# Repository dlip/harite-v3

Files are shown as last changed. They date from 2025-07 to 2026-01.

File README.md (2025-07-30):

# Harite v3 Directional Keyboard

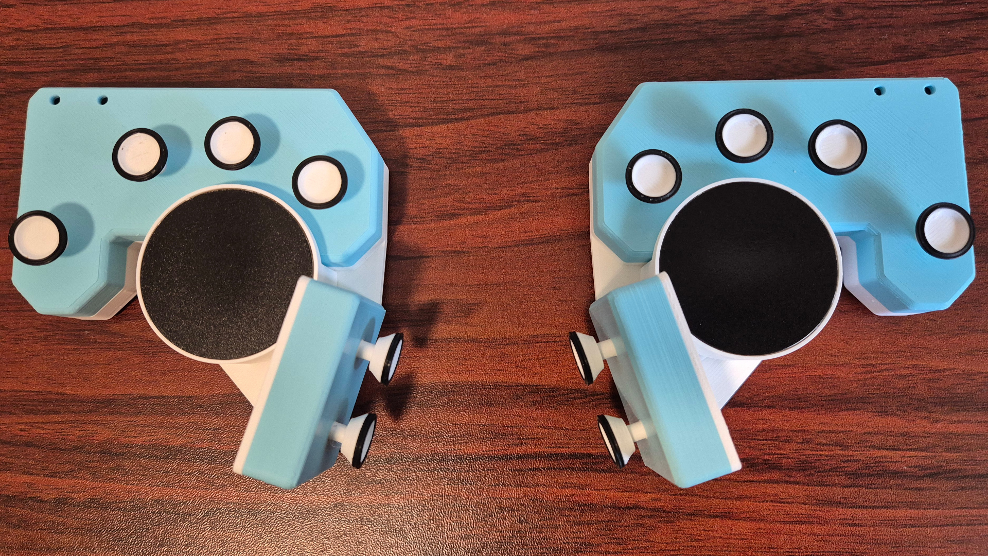
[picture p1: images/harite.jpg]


- 4-way joystick cluster using mouse switches with around 40g actuation force
- 48 total switches
- Bluetooth wireless or USB-C wired
- ZMK studio support for live keymap changes
- Dual trackpads for pointing and scrolling
- Can also support trackballs and analog sticks
- Fully open source and built with open source tools

To make your own, here is a detailed [build guide](./build.md)

## Images

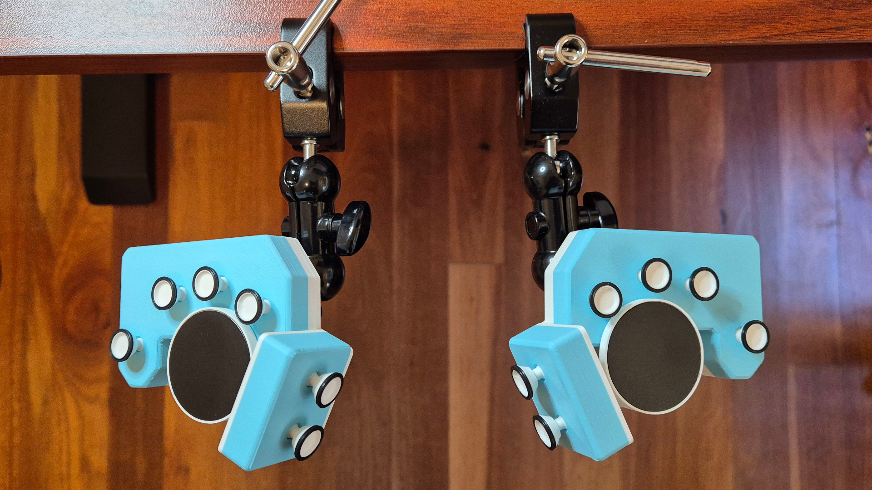
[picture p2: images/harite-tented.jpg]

Tented using the built-in camera mount nut and a SmallRig clamp

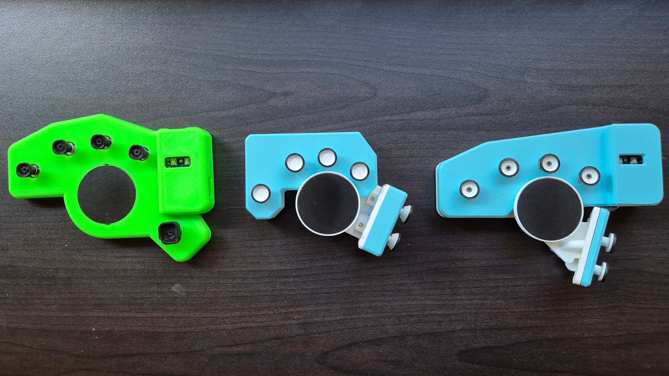
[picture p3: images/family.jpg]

Family Photo

## Videos

- [Jun 5, 2025 - Harite v3 Work in Progress Update](https://youtu.be/gxmuGMYN8iI?si=tEg1mbLF8ET155gk)
- [Jul 20, 2025 - Introducing Harite v3](https://youtu.be/IIlZKIpx4Kw)

## Attributions

Some design elements were inspired by the [CharaChorder CAD Repository](https://github.com/CharaChorder/CAD-CAM)

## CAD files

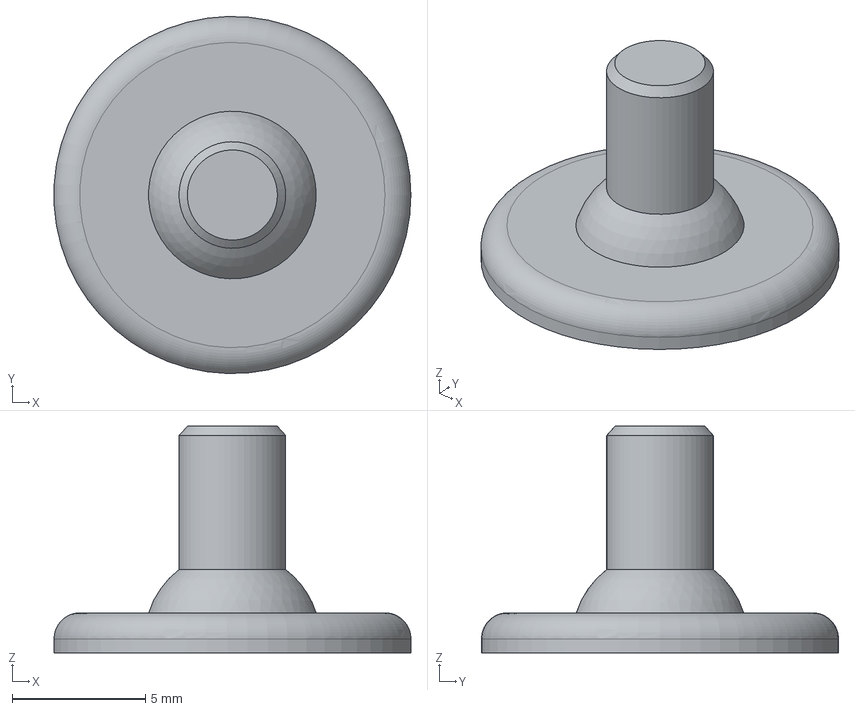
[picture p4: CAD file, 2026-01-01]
freecad/caps-stickstem15.step
13.4 x 13.4 x 8.50 mm

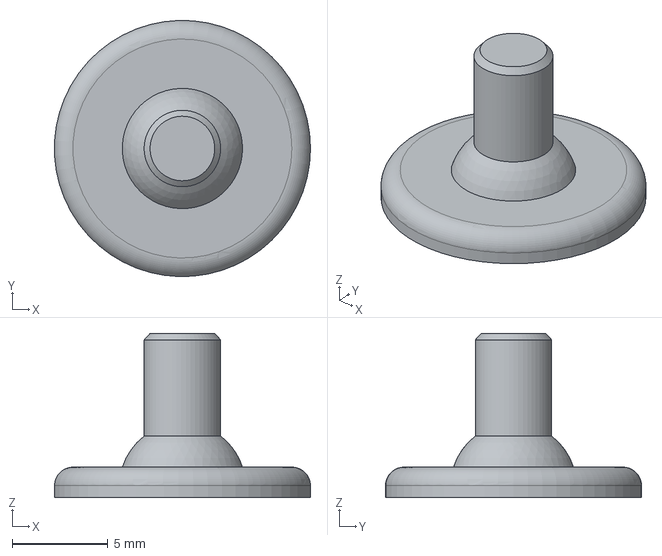
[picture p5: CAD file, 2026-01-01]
freecad/caps-stickstem16.step
13.4 x 13.4 x 8.60 mm

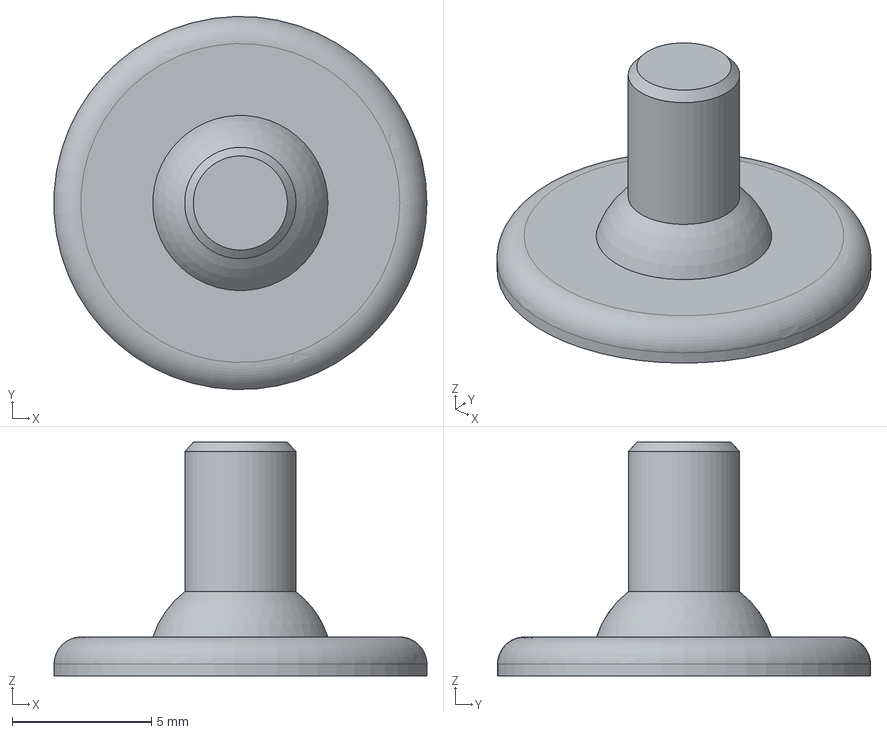
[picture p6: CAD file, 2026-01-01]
freecad/caps-stickstem14.step
13.4 x 13.4 x 8.40 mm

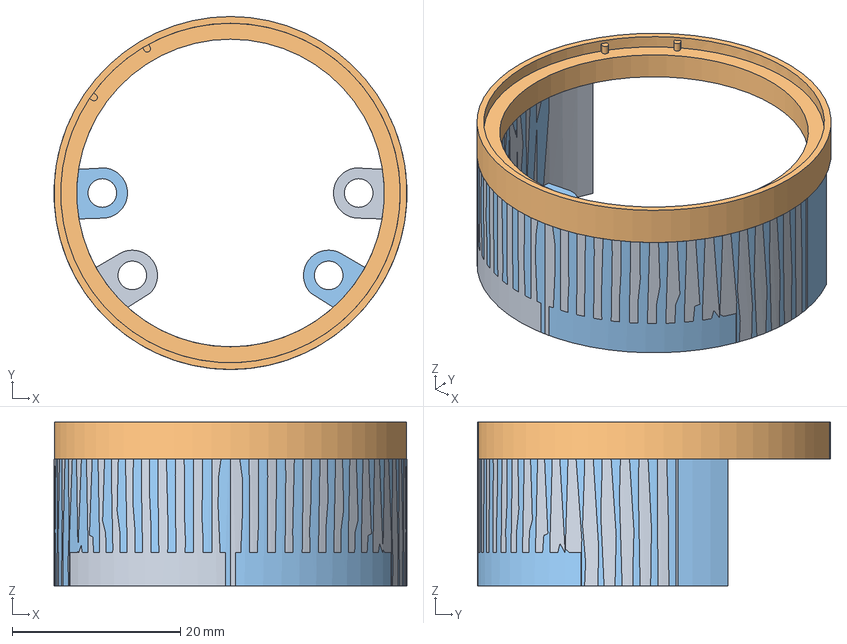
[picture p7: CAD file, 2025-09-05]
freecad/cirque.FCStd
42.0 x 42.0 x 19.5 mm
cirque 40mm x 2
Body001 (Mirror #1)

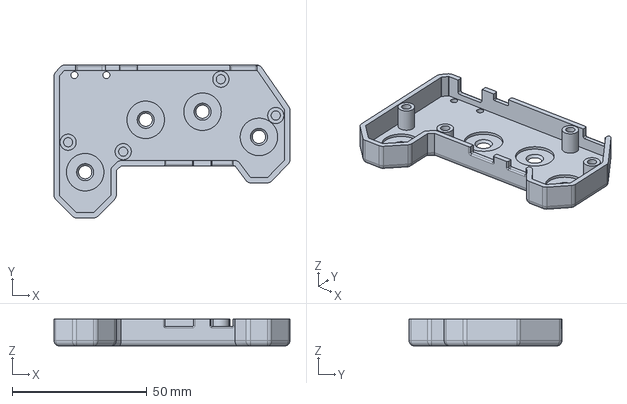
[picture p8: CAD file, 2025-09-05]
freecad/left.FCStd
87.5 x 56.7 x 10.0 mm

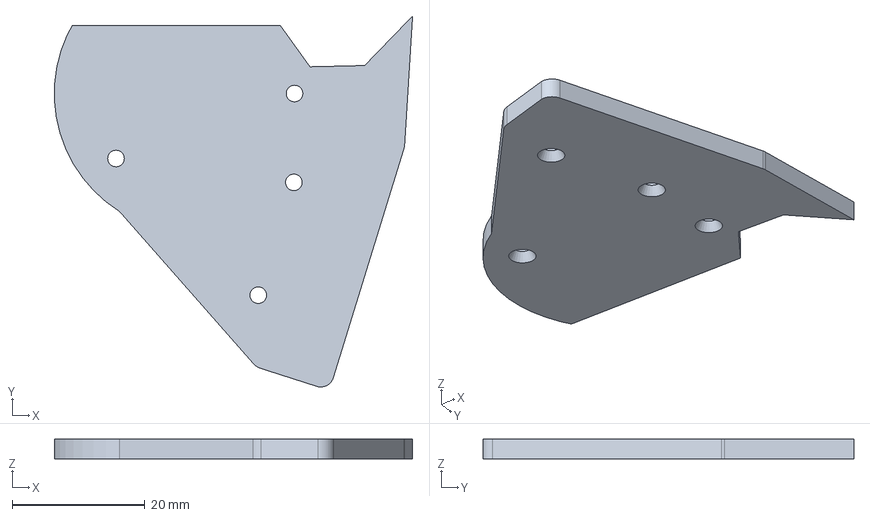
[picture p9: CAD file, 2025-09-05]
freecad/mount.FCStd
54.0 x 56.0 x 3.00 mm

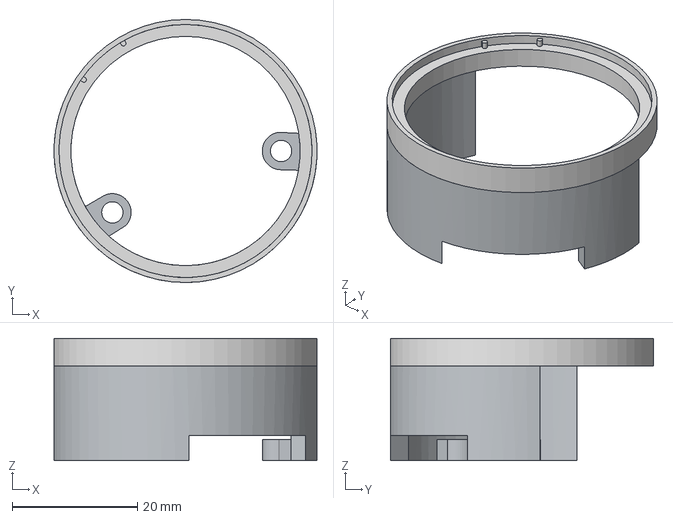
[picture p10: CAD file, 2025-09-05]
freecad/cirque-mount-left.step
42.0 x 42.0 x 19.5 mm
cirque 40mm

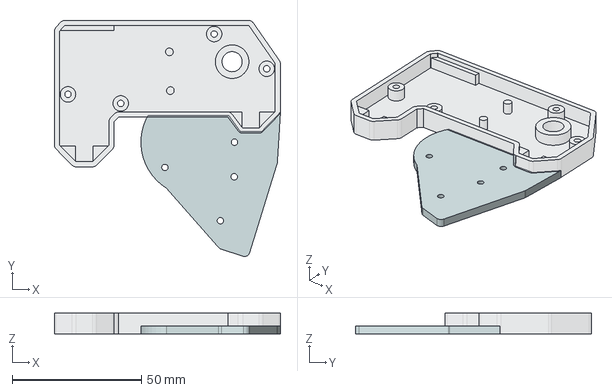
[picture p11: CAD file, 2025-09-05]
freecad/mount-base-mount-left.step
87.5 x 91.4 x 8.00 mm
base

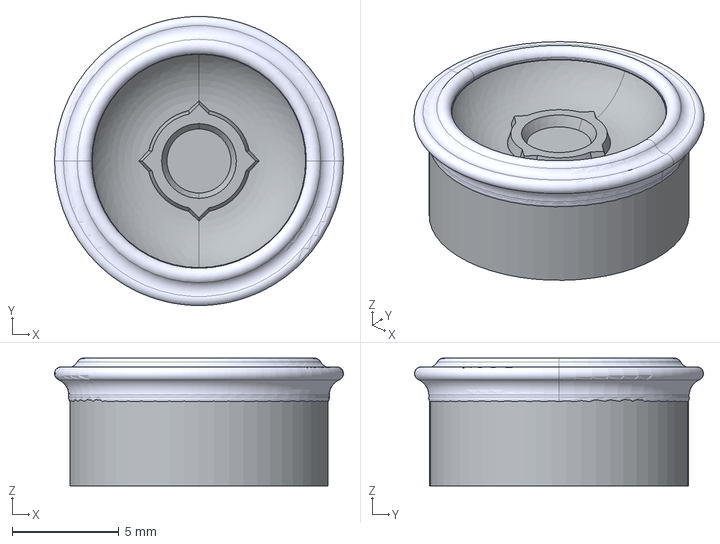
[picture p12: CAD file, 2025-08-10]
freecad/caps-stickmaster-forge-cap-ring.step
13.5 x 13.5 x 6.00 mm
M4GcapRingIncluded002
cap001

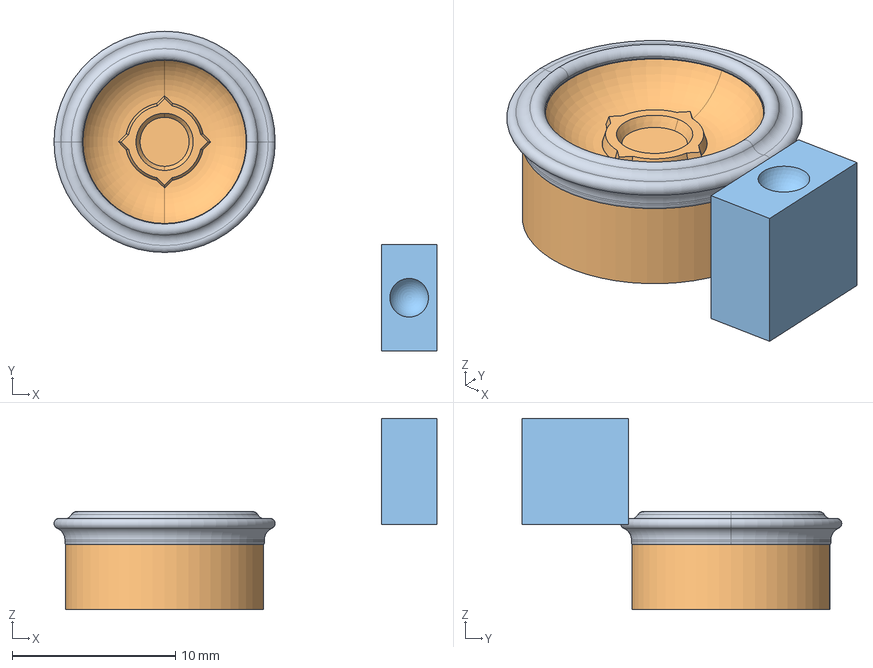
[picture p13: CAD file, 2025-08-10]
freecad/caps.FCStd
23.5 x 19.6 x 11.7 mm
M4GcapRingIncluded002
cap001
pivot-bearing

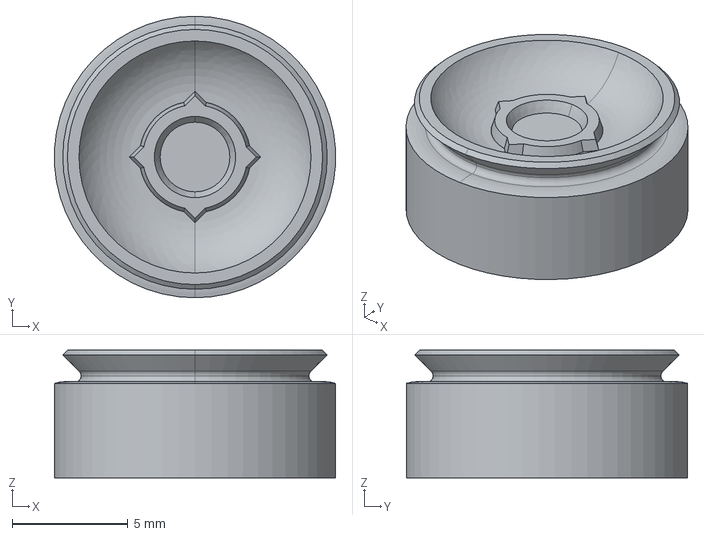
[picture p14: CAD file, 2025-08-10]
freecad/caps-stickmaster-forge-cap.step
12.1 x 12.1 x 5.50 mm

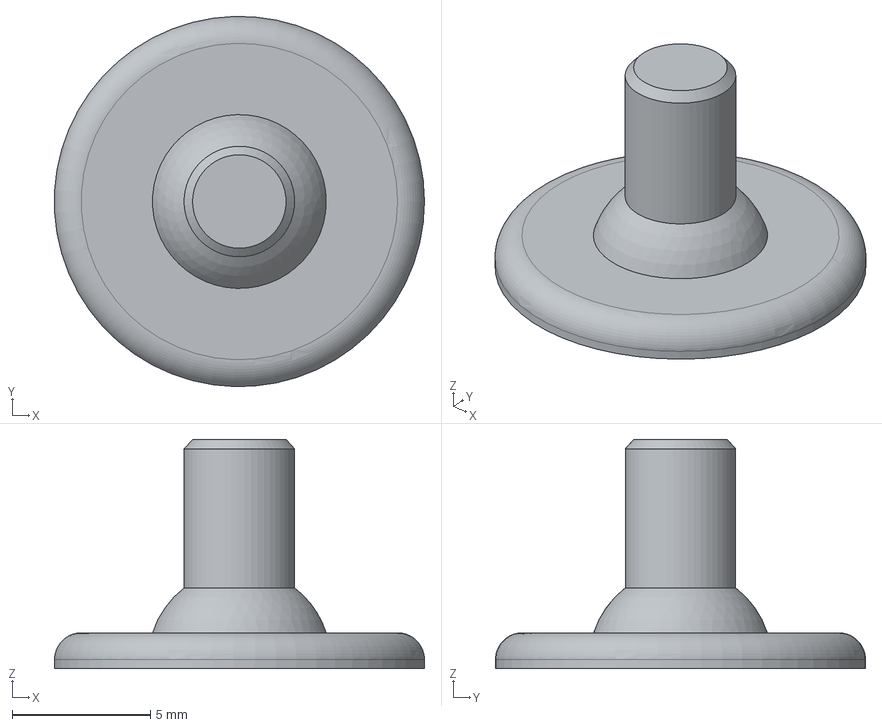
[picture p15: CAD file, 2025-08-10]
freecad/caps-stickstem13.step
13.4 x 13.4 x 8.30 mm

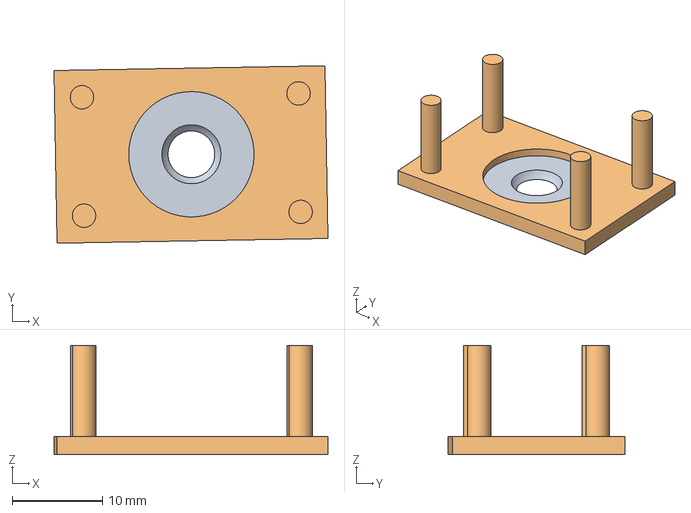
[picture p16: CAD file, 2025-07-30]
freecad/caps-testertop-stick-print.step
30.4 x 19.7 x 12.1 mm
stick-recess
top

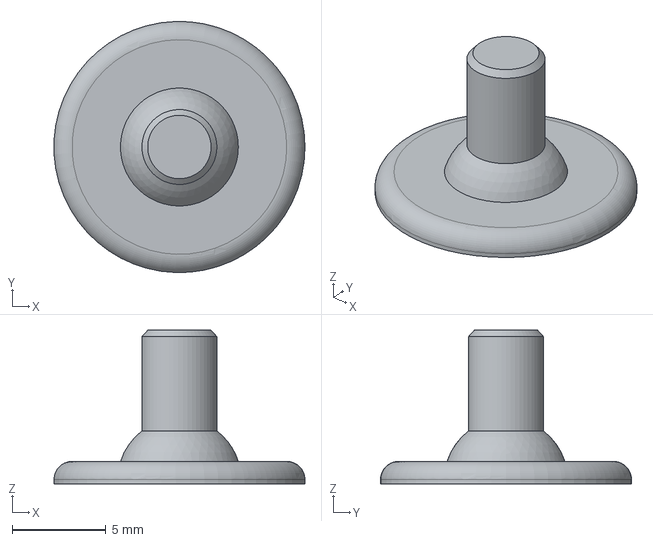
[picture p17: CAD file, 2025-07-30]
freecad/caps-stickstem12.step
13.4 x 13.4 x 8.20 mm

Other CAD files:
freecad/cirque-mount-right.step
freecad/mount-base-mount-right.step
freecad/left-casetop-stick-right-print.step
freecad/caps-stickstem09.step
freecad/caps-pivot-bearing.step
freecad/caps-pivot-bearing.stl
freecad/caps-stickcap.step
freecad/caps-stickcap.stl
freecad/caps-stickmaster-forge-cap-ring.stl
freecad/caps-stickmaster-forge-cap.stl
freecad/caps-stickstem09.stl
freecad/caps-stickstem10.step
freecad/caps-stickstem10.stl
freecad/caps-stickstem11.step
freecad/caps-stickstem11.stl
freecad/caps-stickstem12.stl
freecad/caps-stickstem13.stl
freecad/caps-stickstem14.stl
freecad/caps-stickstem15.stl
freecad/caps-stickstem16.stl
freecad/caps-stickstick-recess.step
freecad/caps-stickstick-recess.stl
freecad/caps-testertop-stick-print.stl
freecad/cirque-mount-left.stl
freecad/cirque-mount-right.stl
freecad/left-casetop-stick-print.step
freecad/left-casetop-stick-print.stl
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

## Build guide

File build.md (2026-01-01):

# Build

## PCB

Due to licensing differences the PCB is in the [harite-v3-pcb](https://github.com/dlip/harite-v3-pcb) repo

## Joysticks

### Joysticks Components

| Name | Qty | Link |
| --- | --- | --- |
| X-Ring of thickness 1.78mm and inner diameter 6.75mm | 12 min (but get 30+ since they break sometimes) | <https://www.aliexpress.com/item/1005006039394059.html> |
| Ball Bearing 2.5mm (steel, ceramic etc.) | 12 | <https://www.aliexpress.com/item/1005008116669372.html> |
| Super Glue | 1 | |

### Joysticks 3D Printed Parts

Due to 3D printing not being perfectly accurate, I have provided various heights for the stem base. I have found 1.1 mm to work most of the time, so start with that and go up if it feels loose or go down if it feels stiff and crunchy.

| Name | Qty | Layer Height | Infill | Supports | Link |
| --- | --- | --- | --- | --- | --- |
| Pivot Base | 12 | 0.1mm | 10% | No | [Step](./freecad/caps-pivot-bearing.step) [Stl](./freecad/caps-pivot-bearing.stl) |
| Stem 0.9mm Base | 12 total stems | 0.1mm | 10% | No | [Step](./freecad/caps-stickstem09.step) [Stl](./freecad/caps-stickstem09.stl) |
| Stem 1.0mm Base | 12 total stems | 0.1mm | 10% | No | [Step](./freecad/caps-stickstem10.step) [Stl](./freecad/caps-stickstem10.stl) |
| Stem 1.1mm Base | 12 total stems | 0.1mm | 10% | No | [Step](./freecad/caps-stickstem11.step) [Stl](./freecad/caps-stickstem11.stl) |
| Stem 1.2mm Base | 12 total stems | 0.1mm | 10% | No | [Step](./freecad/caps-stickstem12.step) [Stl](./freecad/caps-stickstem12.stl) |
| Stem 1.3mm Base | 12 total stems | 0.1mm | 10% | No | [Step](./freecad/caps-stickstem13.step) [Stl](./freecad/caps-stickstem13.stl) |
| Stem 1.4mm Base | 12 total stems | 0.1mm | 10% | No | [Step](./freecad/caps-stickstem14.step) [Stl](./freecad/caps-stickstem14.stl) |
| Stem 1.5mm Base | 12 total stems | 0.1mm | 10% | No | [Step](./freecad/caps-stickstem15.step) [Stl](./freecad/caps-stickstem15.stl) |
| Stem 1.6mm Base | 12 total stems | 0.1mm | 10% | No | [Step](./freecad/caps-stickstem16.step) [Stl](./freecad/caps-stickstem16.stl) |

#### Caps

| Name | Qty | Layer Height | Infill | Supports | Link |
| --- | --- | --- | --- | --- | --- |
| Harite Cap | 12 total caps | 0.1mm | 10% | No | [Step](./freecad/caps-stickcap.step) [Stl](./freecad/caps-stickcap.stl) |
| Master Forge Cap | 12 total caps | 0.1mm | 10% | No | [Step](./freecad/caps-stickmaster-forge-cap.step) [Stl](./freecad/caps-stickmaster-forge-cap.stl) |
| Master Forge Cap with ring (for printing using rubber) | 12 total caps | 0.1mm | 10% | No | [Step](./freecad/caps-stickmaster-forge-cap-ring.step) [Stl](./freecad/caps-stickmaster-forge-cap-ring.stl) |

### Joysticks Preparation

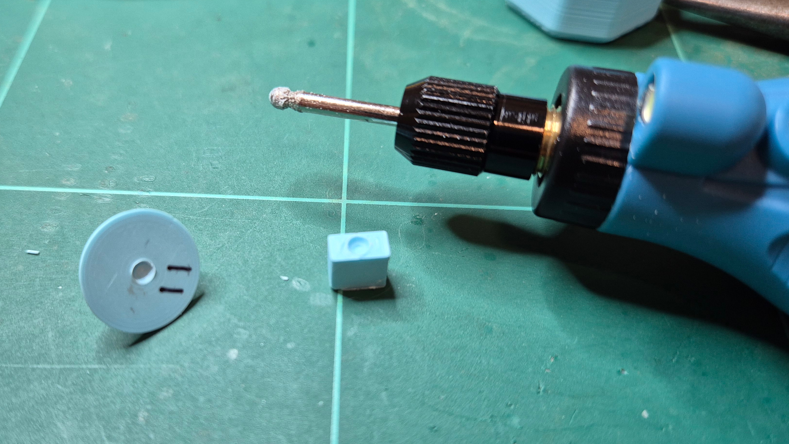
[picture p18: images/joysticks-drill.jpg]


Since 3D printing is rough and inaccurate, especially with small, round parts some post processing is required.
I recommend a rotary tool with 2.3mm spherical tip like this [Hardell](https://www.amazon.com.au/gp/product/B0DFTJFYY8) one, or a Dremel.
An alternative is using a 2mm drill bit, but the result wont be as smooth.

- Widen the hole in the pivot base little by little, and sit the bearing in the crevice. The total height of the pivot base + bearing should be around 8.0mm, which you can measure with digital calipers. You can then super glue it in. I find using the blunt side of a toothpick a good tool to apply the glue with.
- Widen the hole in the stem little by little, until it sits flush on the 4 switches + stem. If there is any rocking back and forth, drill further. There should be a small deadzone when pressing down in the middle onto the bearing, if switches are triggered you've gone too far and should print a new stem.
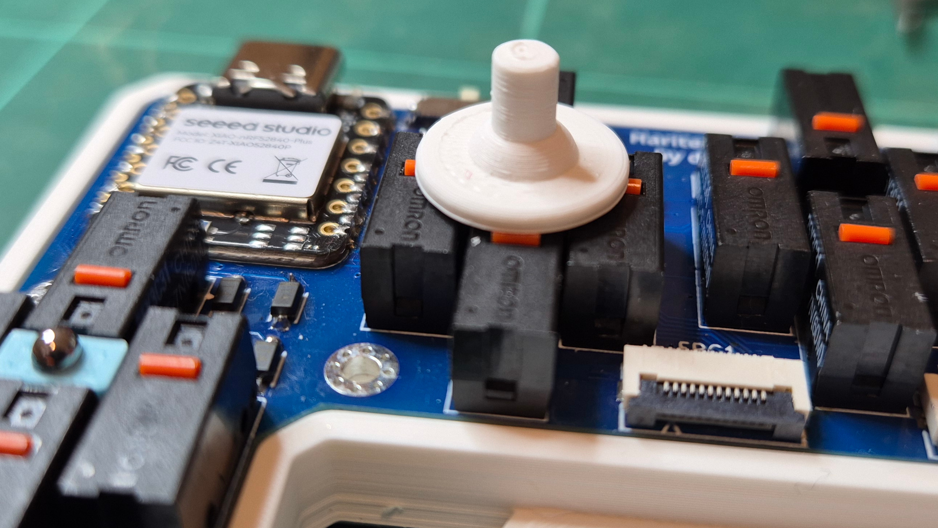
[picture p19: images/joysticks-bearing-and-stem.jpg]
  
- To fit the X-Rings use needle nose pliers to stretch them over the sides as shown, then use some blunt tweezers to pull then out to the front and back sides. Hold the ring down on top with the tweezers as you release the pliers and pull them out. Be careful the ring twist doesn't twist.
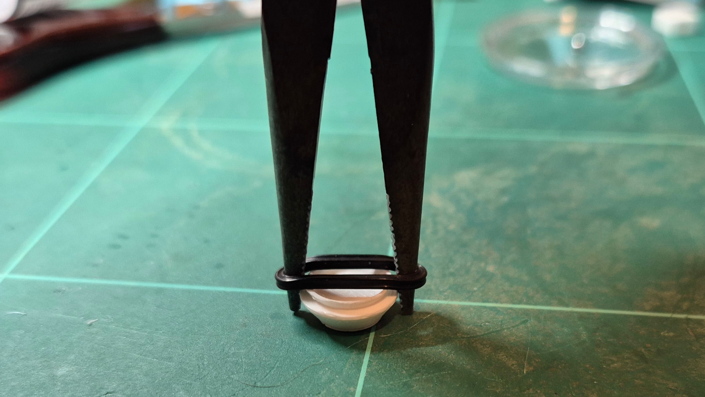
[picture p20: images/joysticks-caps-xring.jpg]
  

## Tester

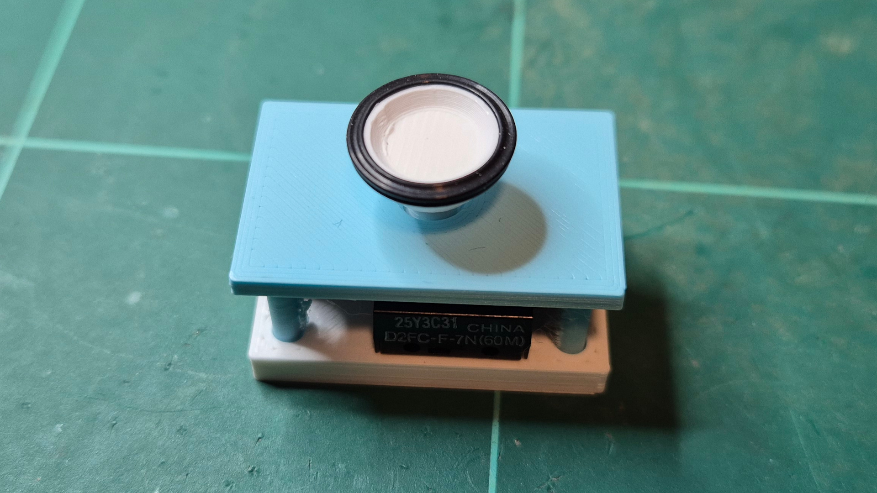
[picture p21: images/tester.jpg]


This is handy if you just want to test out switches or tweak the design

### Tester 3D Printed Parts

| Name | Qty | Layer Height | Infill | Supports | Link |
| --- | --- | --- | --- | --- | --- |
| Tester Base | 1 | 0.2mm | 10% | No | [Step](./freecad/thumb-cluster-test-base.step) [Stl](./freecad/thumb-cluster-test-base.stl) |
| Tester Top  | 1 | 0.1mm | 10% | No | [Step](./freecad/caps-testertop-stick-print.step) [Stl](./freecad/caps-testertop-stick-print.stl) |

## Dual Cirque Configuration

### Dual Cirque Components

| Name | Qty | Link |
| --- | --- | --- |
| Cirque 40mm Trackpads TM040040-2024-302 with flat overlay | 2 | <https://au.mouser.com/ProductDetail/Cirque/TM040040-2024-302> |
| 12 pin FFC cable type-A 0.5 pitch 6cm length | 2 | <https://www.aliexpress.com/item/10000013182312.html> |
| M2 Stainless Steel Countersunk Screw 10mm | 8 | <https://www.aliexpress.com/item/1005007257158892.html> |
| M2 Stainless Steel Countersunk Screw 6mm | 16  | <https://www.aliexpress.com/item/1005007257158892.html> |
| M2 knurled insert nuts 3mm length 3.5mm OD | 24  | <https://www.aliexpress.com/item/1005008897571758.html> |
| 1/4-20 8mm OD 6mm height Knurled Insert Nut | 2 | <https://www.aliexpress.com/item/1005005225137961.html> |
| Rubber Feet 1cm diameter | 12  | |
| Blu Tak | 1 | |

### Dual Cirque 3D Printed Parts

| Name | Qty | Layer Height | Infill | Supports | Link |
| --- | --- | --- | --- | --- | --- |
| Mount Base Left | 1 | 0.2mm | 30% | No | [Step](./freecad/mount-base-mount-left.step) [Stl](./freecad/mount-base-mount-left.stl) |
| Mount Base Right | 1 | 0.2mm | 30% | No | [Step](./freecad/mount-base-mount-right.step) [Stl](./freecad/mount-base-mount-right.stl) |
| Top Left | 1 | 0.1mm | 10% | No | [Step](./freecad/left-casetop-stick-print.step) [Stl](./freecad/left-casetop-stick-print.stl) |
| Top Right | 1 | 0.1mm | 10% | No | [Step](./freecad/left-casetop-stick-right-print.step) [Stl](./freecad/left-casetop-stick-right-print.stl) |
| Thumb Cluster Base | 2 | 0.1mm | 10% | No | [Step](./freecad/thumb-cluster-thumb-cluster-casebase-print.step) [Stl](./freecad/thumb-cluster-thumb-cluster-casebase-print.stl) |
| Thumb Cluster Top  | 2 | 0.1mm | 10% | No | [Step](./freecad/thumb-cluster-thumb-cluster-casetop-stick-print.step) [Stl](./freecad/thumb-cluster-thumb-cluster-casetop-stick-print.stl) |
| Cirque Mount Left  | 1 | 0.1mm | 10% | Yes | [Step](./freecad/cirque-mount-left.step) [Stl](./freecad/cirque-mount-left.stl) |
| Cirque Mount Right | 1 | 0.1mm | 10% | Yes | [Step](./freecad/cirque-mount-right.step) [Stl](./freecad/cirque-mount-right.stl) |

### Dual Cirque Assembly

- Melt M3 insert nuts into top of the cases, thumb cluster base and cirque mount. 180c is a good iron temperature.
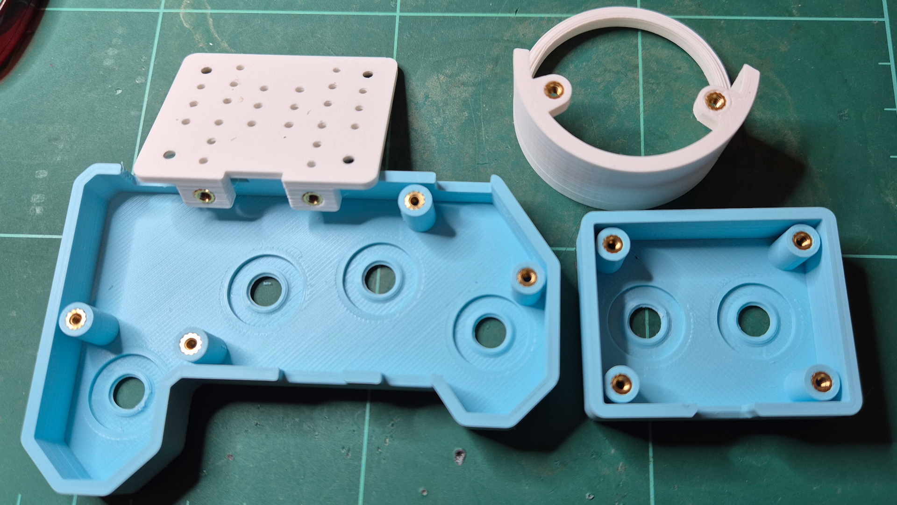
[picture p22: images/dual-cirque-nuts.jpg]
  
- Melt 1/4-20 insert nut into back of the base. 330c is a good iron temperature. Be sure not to go too far below the surface as it may offset the PCB.
- Add rubber feet to base.
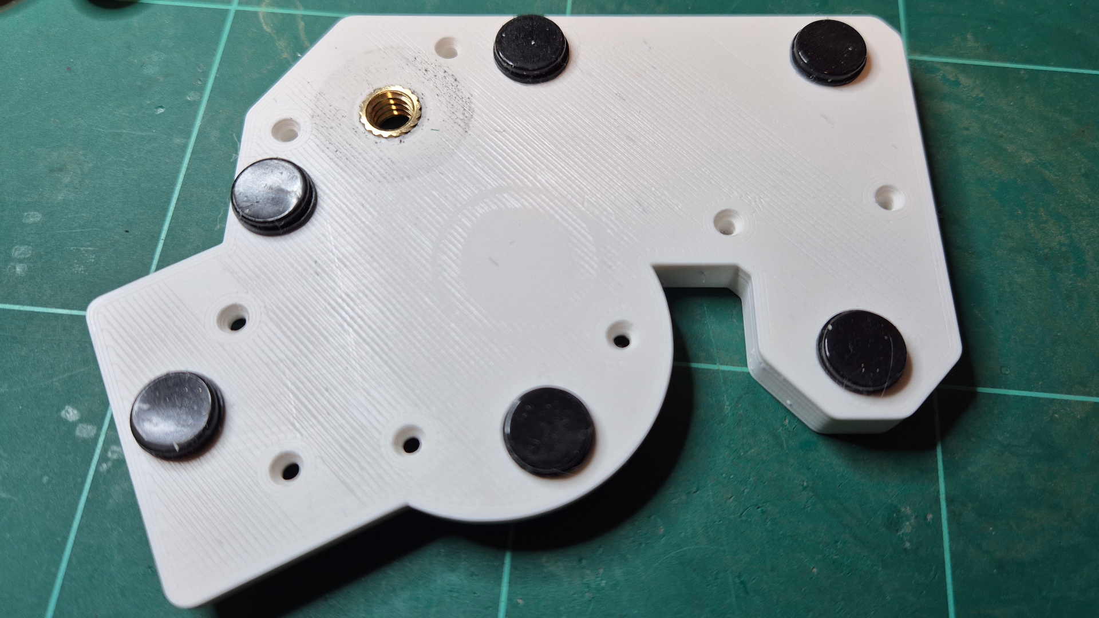
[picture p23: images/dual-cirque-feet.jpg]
  

- Push joystick stems onto caps through the holes in the top of the cases
- Use Blu Tak to help keep Cirque in place. Roll 3 thin 1cm noodles and squash them down, avoiding the alignment notches at the top left.
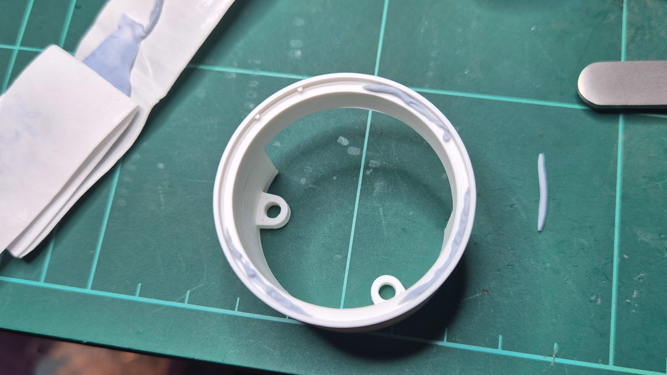
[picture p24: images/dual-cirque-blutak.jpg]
  
- Connect FFC cables to the thumb cluster and Cirque.
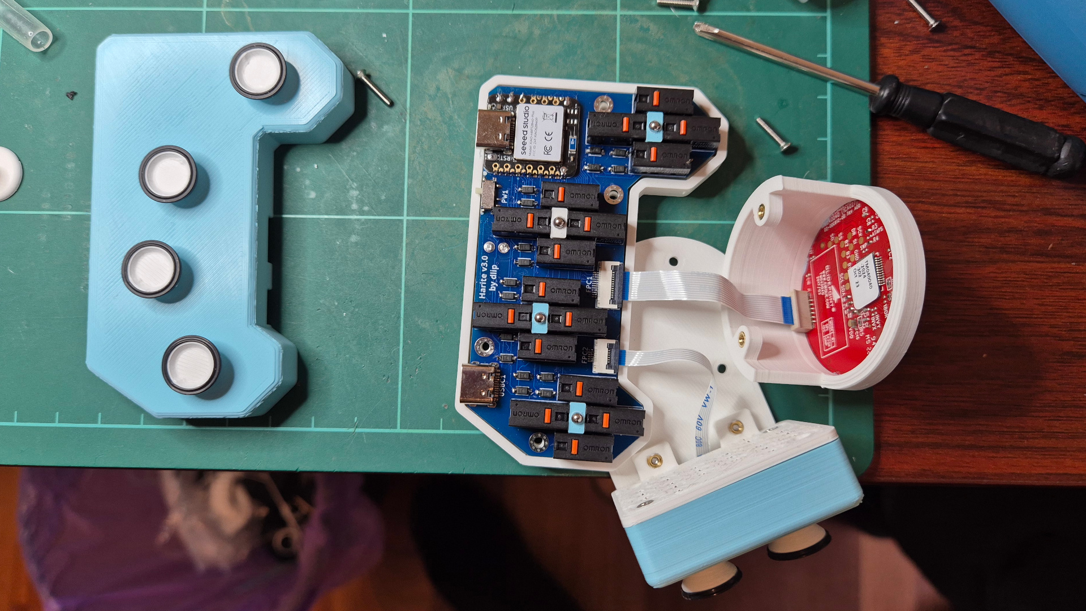
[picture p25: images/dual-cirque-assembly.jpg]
  
- Be sure to run the FFC cable under the notch of the Cirque to keep it flat.
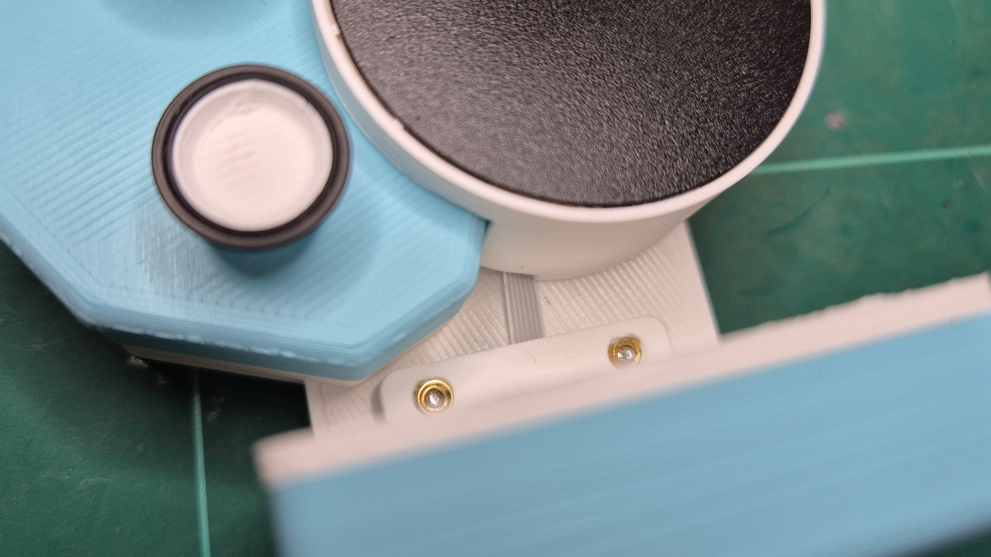
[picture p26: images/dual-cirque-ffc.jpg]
  
- Screw main top on using 10mm screws, then the thumb cluster base and cirque mount with 6mm screws
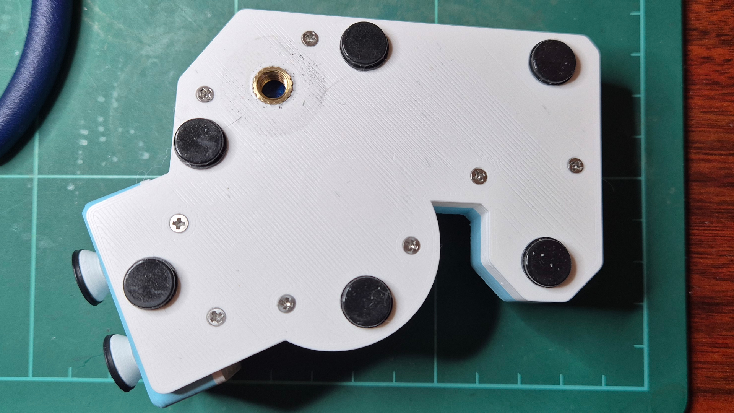
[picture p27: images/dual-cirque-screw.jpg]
  
- Done!
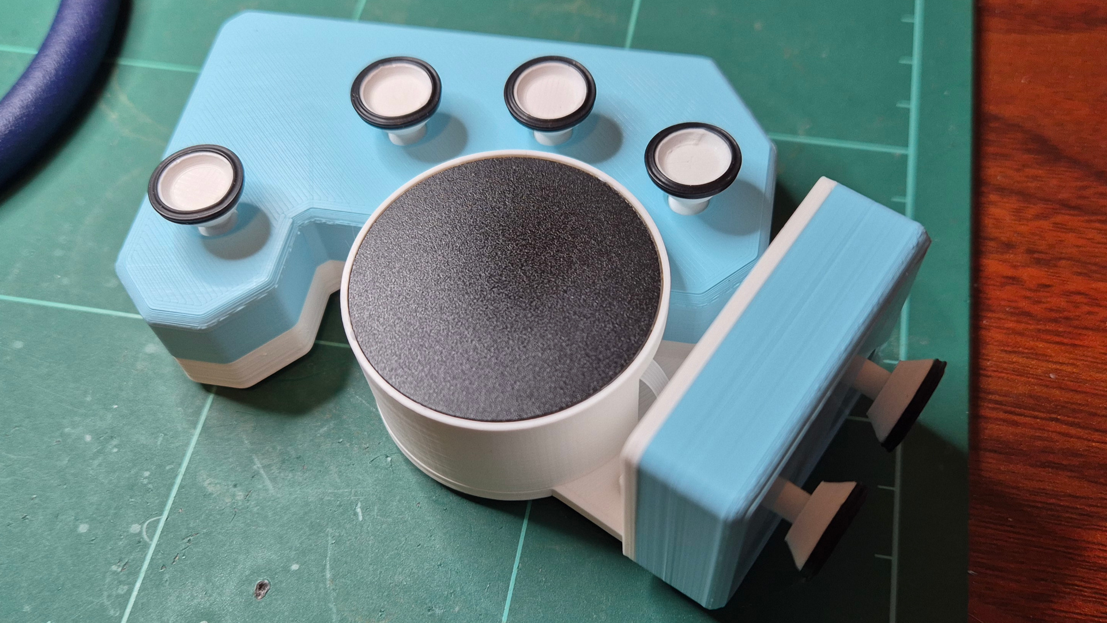
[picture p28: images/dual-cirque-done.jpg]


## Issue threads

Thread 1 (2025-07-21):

Hello from CharaChorder

rileykeen, 2025-07-21:
Hey Dane,

Love the project and here to support however I can! I noticed your project seems heavily based on our open source designs which you're aware are available here: (https://github.com/CharaChorder/CAD-CAM/) We’re always glad to see new projects like this, but any work based on our open source designs should be credited/published with proper attributions. Thank you and please let us know if there's any other way we can support further development. We wish you great success on this project, and to anyone else who aims to help normalize typing in 3D! https://youtu.be/eH87_pgb8yE

-Riley
This text was typed at the speed of thought.®

dlip, 2025-07-21:
Hi @rileykeen,

I appreciate your videos, and was inspired to make my own mouse/joystick cluster from yours and other arcade joystick design videos, but I am confident my design is my 100% my own as I have spent many hours prototyping this without using your design files. From what I can see in the videos, my mouse switches are a different form factor, arranged in a different orientation, the stem shape is different, uses bearings, and doesn't even support the 3D center press that is featured in your video.

While I may have looked at your repo a while ago to see how you connect the xring to the keycap, I modeled a lip on my own keycap which is a pretty minor feature and didn't use any of your files, so I don't believe it should require attribution. The licence on your repository is unfortunately not compatible with my GPL one and so I have been very careful not copy directly from it.

I'm happy to give you credit though, and have said on my videos that some of the inspiration has come from watching your videos on the CharaChorder/Master Forge. I hope my designs can also inspire you in return.

rileykeen, 2025-07-21:
Yes, I think what happened is pretty much as you have described it here. It seems like you wanted to use our design without our licence so you recreated elements of it to avoid using our licence. In doing this, I think you may have had some broader misunderstanding on the purpose & intent of a license. Changing switch orientation or remodeling a lip does not make someone else's design '100% your own’. If this would not qualify for attribution I cannot imagine anything that would. We are pretty lax as far as this stuff goes and this is the 1st I've ever had to reach out to request attribution like this. I really don't think there's any malicious intent here, but it's important to understand that republishing anything under a license different from the original has broader implications outside of your project.

dlip, 2025-07-21:
@rileykeen I do not mean to disregard the effort of you and your team, I'm happy to replace the xring feature since I did look at your repo before modelling that. Would that be sufficient to unbind this project from the terms of that licence?

dlip, 2025-07-21:
@rileykeen ok I'm happy to credit you with the parts that could have been inspired from your repo. But I don't want to change the licence from GPL for my whole repo though since I've developed the majority of that on my own. Would you be satisfied if I moved those 3D cad files to a separate repo which would be under the CharaChorder BY-SA-CR License?

rileykeen, 2025-07-22:
Probably a separate repo is unnecessary; multi-licensing is pretty common these days though I'll defer from getting involved with decisions regarding your repo organisation atm as finding agreement on what belongs where might take considerable time. Thanks for the attribution, and hey I really mean it when I say to reach out if there's anything I can do to support.🤠 All the best!

rileykeen, 2025-07-22:
Our repo does contain PCB designs, though again I'll defer per my last message. I agree that licensing the 3D is appropriate

dlip, 2025-07-23:
@rileykeen I've made the changes we discussed. The attribution is here https://github.com/dlip/harite-v3?tab=readme-ov-file#attributions

Let me know if that works for you

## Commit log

2025-07-23 Add Harite v3
    [caps-pivot-bearing.step, caps-pivot-bearing.stl, caps-stickcap.step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]
2025-07-23 Fix bearing size
2025-07-30 Harite v3.1
    - Refinement of almost all parts, except for cap top. The joysticks feel
    tighter with less wobbly. It is definitely worth reprinting everything.
    - Tolerance around base reduced from 0.4mm to 0.2mm. I found the
    joysticks to be very sensitive to even a small offset from the centre,
    they would crunch in one direction and the the actuation force would be
    higher. There is still some wiggle room but this makes it a lot easier
    to find the best position.
    - Simplified joystick recess to reduce friction surface area.
    - Added holes on top to push reset and see charging led on MCU.
    Comfortably fits a 2.3mm diameter toothpick.
    - Added slots to the Cirque and thumb cluster base to help hide th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
    [caps-pivot-bearing.stl, caps-stickstem09.step, caps-stickstem09.stl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]
2025-08-10 Add 1.3mm stem
    [caps-stickstem13.step, caps-stickstem13.stl]
2025-08-10 Add Master Forge cap
    [caps-stickmaster-forge-cap.step, caps-stickmaster-forge-cap.stl, caps.FCStd]
2025-08-10 Add Master Forge Cap with ring
    [caps-stickmaster-forge-cap-ring.step, caps-stickmaster-forge-cap-ring.stl, caps.FCStd]
2025-09-05 Move thumb mount downwards (#3)
    [cirque-mount-left.step, cirque-mount-left.stl, cirque-mount-right.step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]
2026-01-01 Add longer stems
    [caps-stickstem14.step, caps-stickstem14.stl, caps-stickstem15.step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]
